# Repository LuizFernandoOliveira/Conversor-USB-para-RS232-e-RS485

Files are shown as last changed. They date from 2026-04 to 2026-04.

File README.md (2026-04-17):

# Conversor USB para RS232 e RS485




## Descrição
Esta PCB trata-se de um circuito eletrônico que transforma uma única porta USB em múltiplos canais de comunicação serial industrial RS232 e/ou RS485.

<p align="center">
  usb2RS232RS485
</p>

---

## Descrições técnicas

- Interface USB: Dispositivo USB High-Speed de 480Mbps;
- Possui quatro canais RS232 (1 ao 4) e quatro canais RS485 (1 ao 4);
- Taxa de Transmissão (Baud Rate): Variável de 1200bps até 6Mbps;
- Alimentação Principal: Requer apenas 3.3V;
- Possui pinos de alimentação de saída de 3.3V e 5V;
- Buffering (FIFO):
  - RX FIFO: 2048 bytes por UART.
  - TX FIFO: 1024 bytes por UART.
- Configurações UART:
  - Bits de Dados: 8 bits;
  - Paridade: Ímpar, Par e Nenhuma;
  - Bits de Parada: 1 ou 2.

---

## Estrutura do repositório
Os arquivos de hardware foram desenvolvidos utilizando o KiCad 9.0.
- **`.kicad_pcb`**: Layout da placa de circuito impresso (Board).
- **`.kicad_sch`**: Esquemático eletrônico do sistema (Schematic).
- **`.kicad_pro`**: Gerenciador de projeto do KiCad (Project).

---

## Autor
**Dr. Luiz Fernando Pinto de Oliveira**

*Engenheiro Eletrônico especializado em Sistemas Embarcados e Ultra-Low Power.*
- **Website:** [FAPLO](https://faplo.webnode.page/)
- **LinkedIn:** [lfpo](https://www.linkedin.com/in/lfpo/)

---

Shield: [][cc-by-nc-nd]

This work is licensed under a
[Creative Commons Attribution-NonCommercial-NoDerivs 4.0 International License][cc-by-nc-nd].

[][cc-by-nc-nd]

[cc-by-nc-nd]: http://creativecommons.org/licenses/by-nc-nd/4.0/
[cc-by-nc-nd-image]: https://licensebuttons.net/l/by-nc-nd/4.0/88x31.png
[cc-by-nc-nd-shield]: https://img.shields.io/badge/License-CC%20BY--NC--ND%204.0-lightgrey.svg

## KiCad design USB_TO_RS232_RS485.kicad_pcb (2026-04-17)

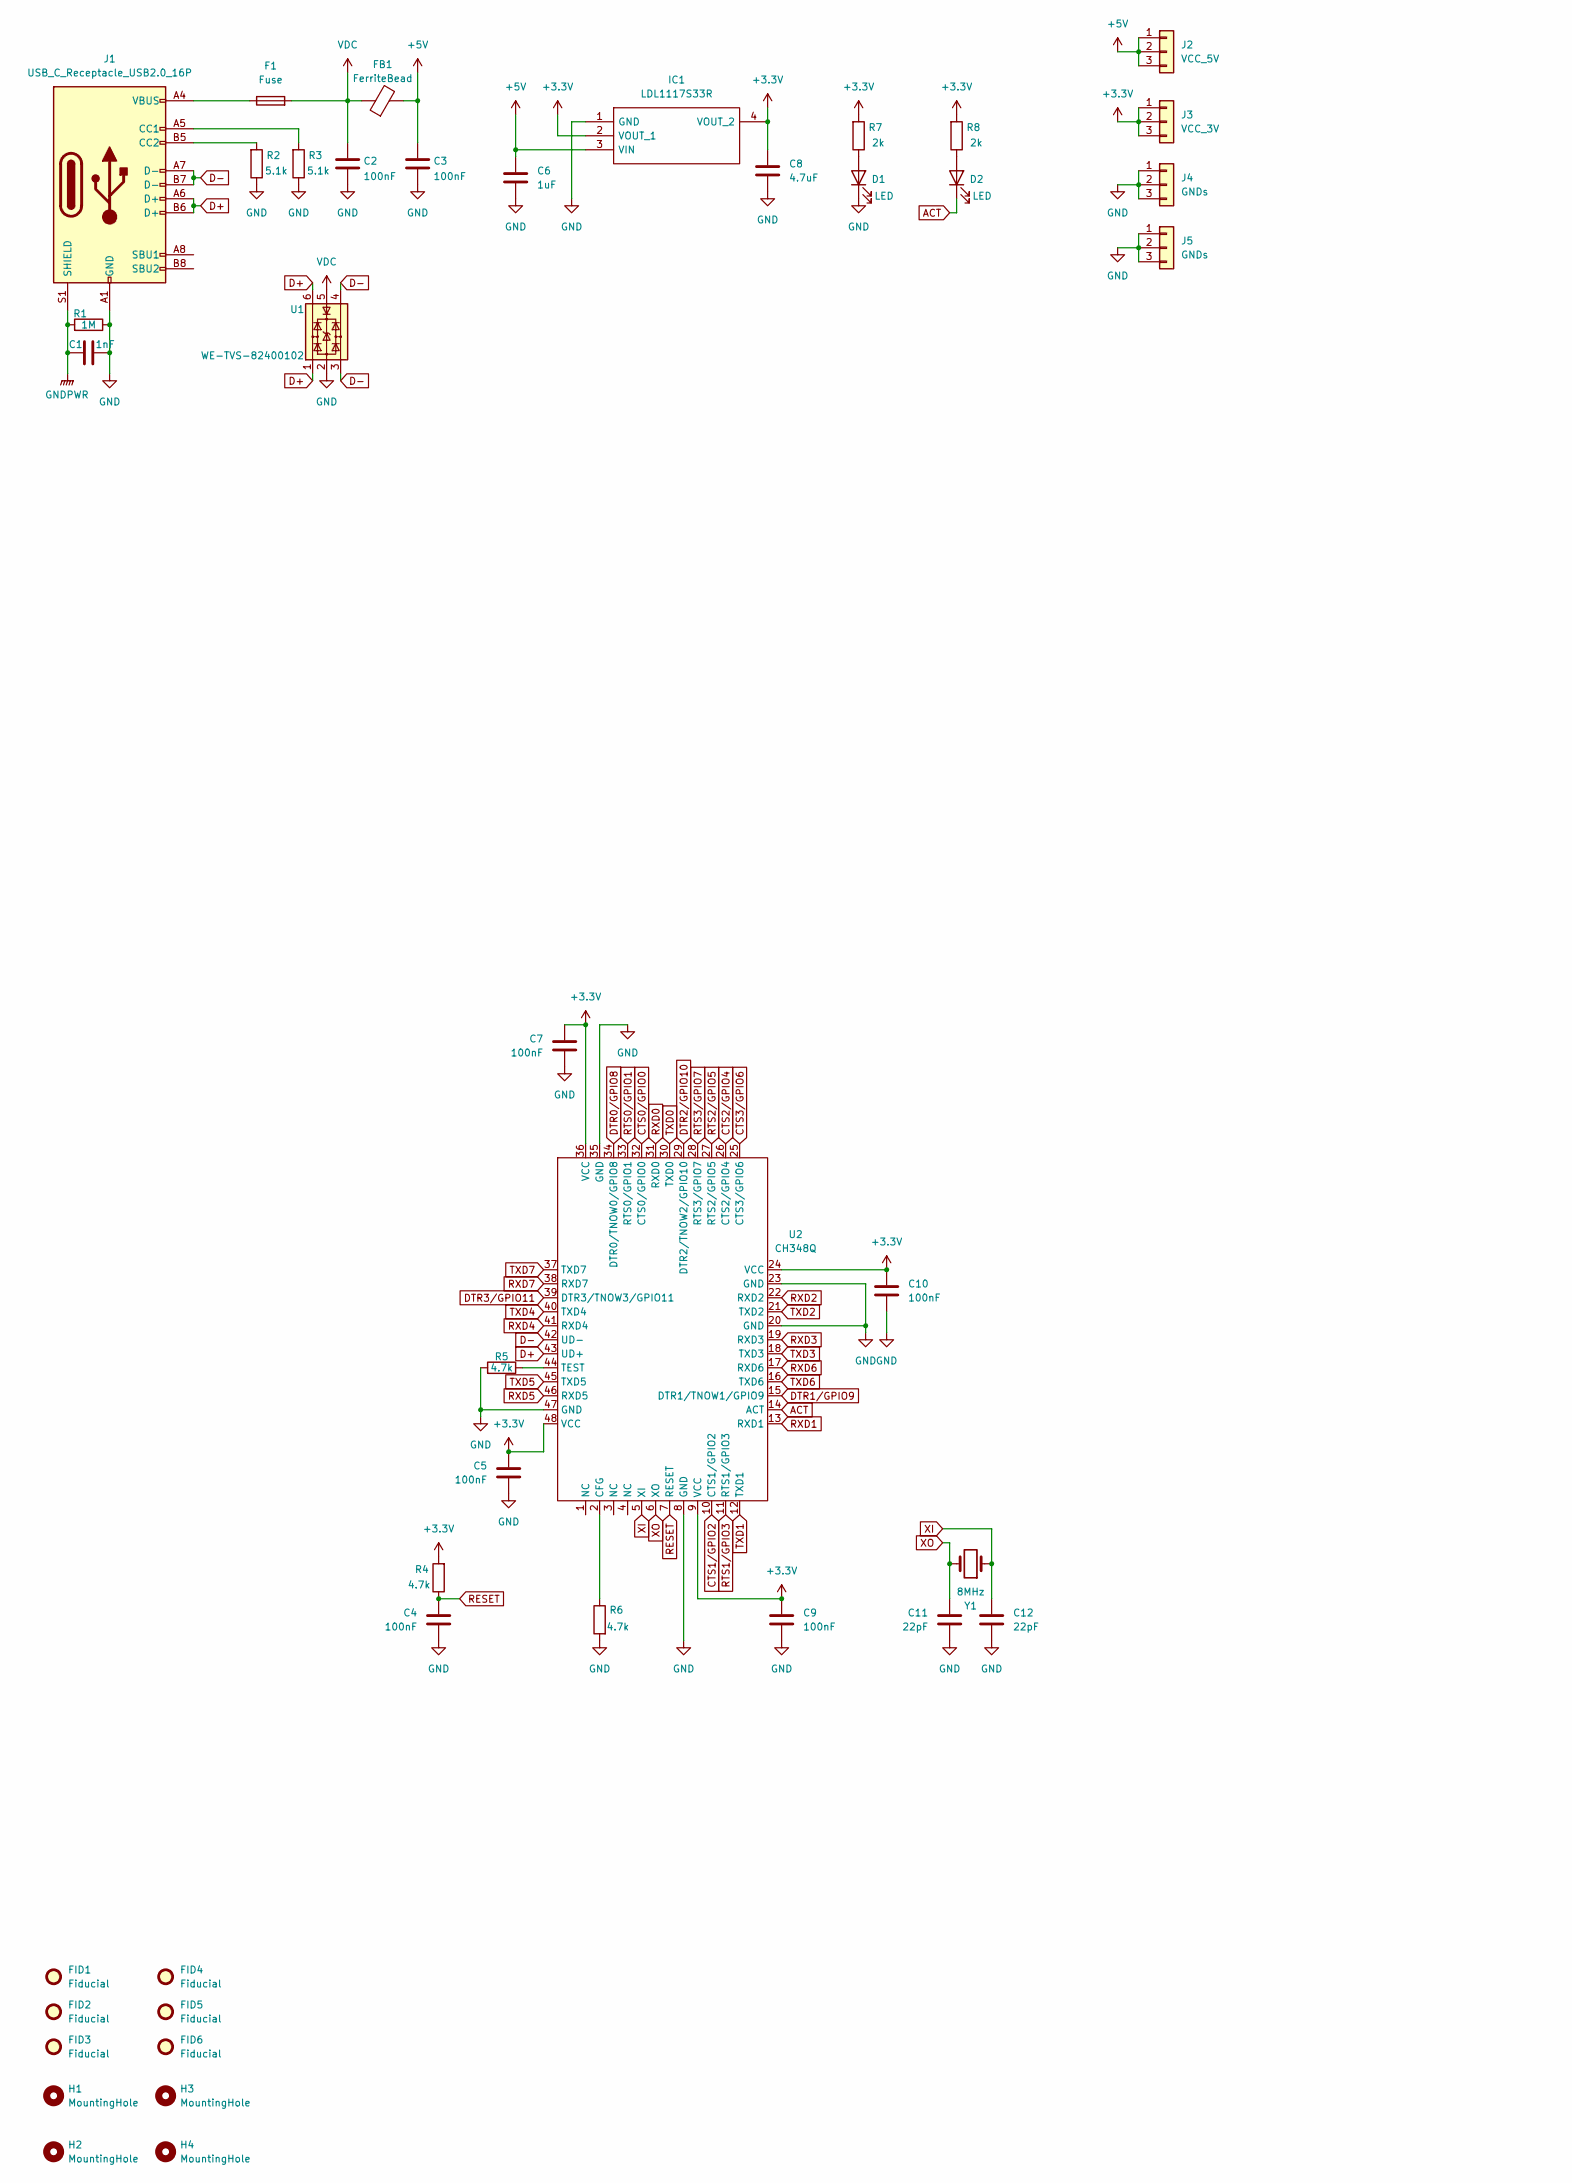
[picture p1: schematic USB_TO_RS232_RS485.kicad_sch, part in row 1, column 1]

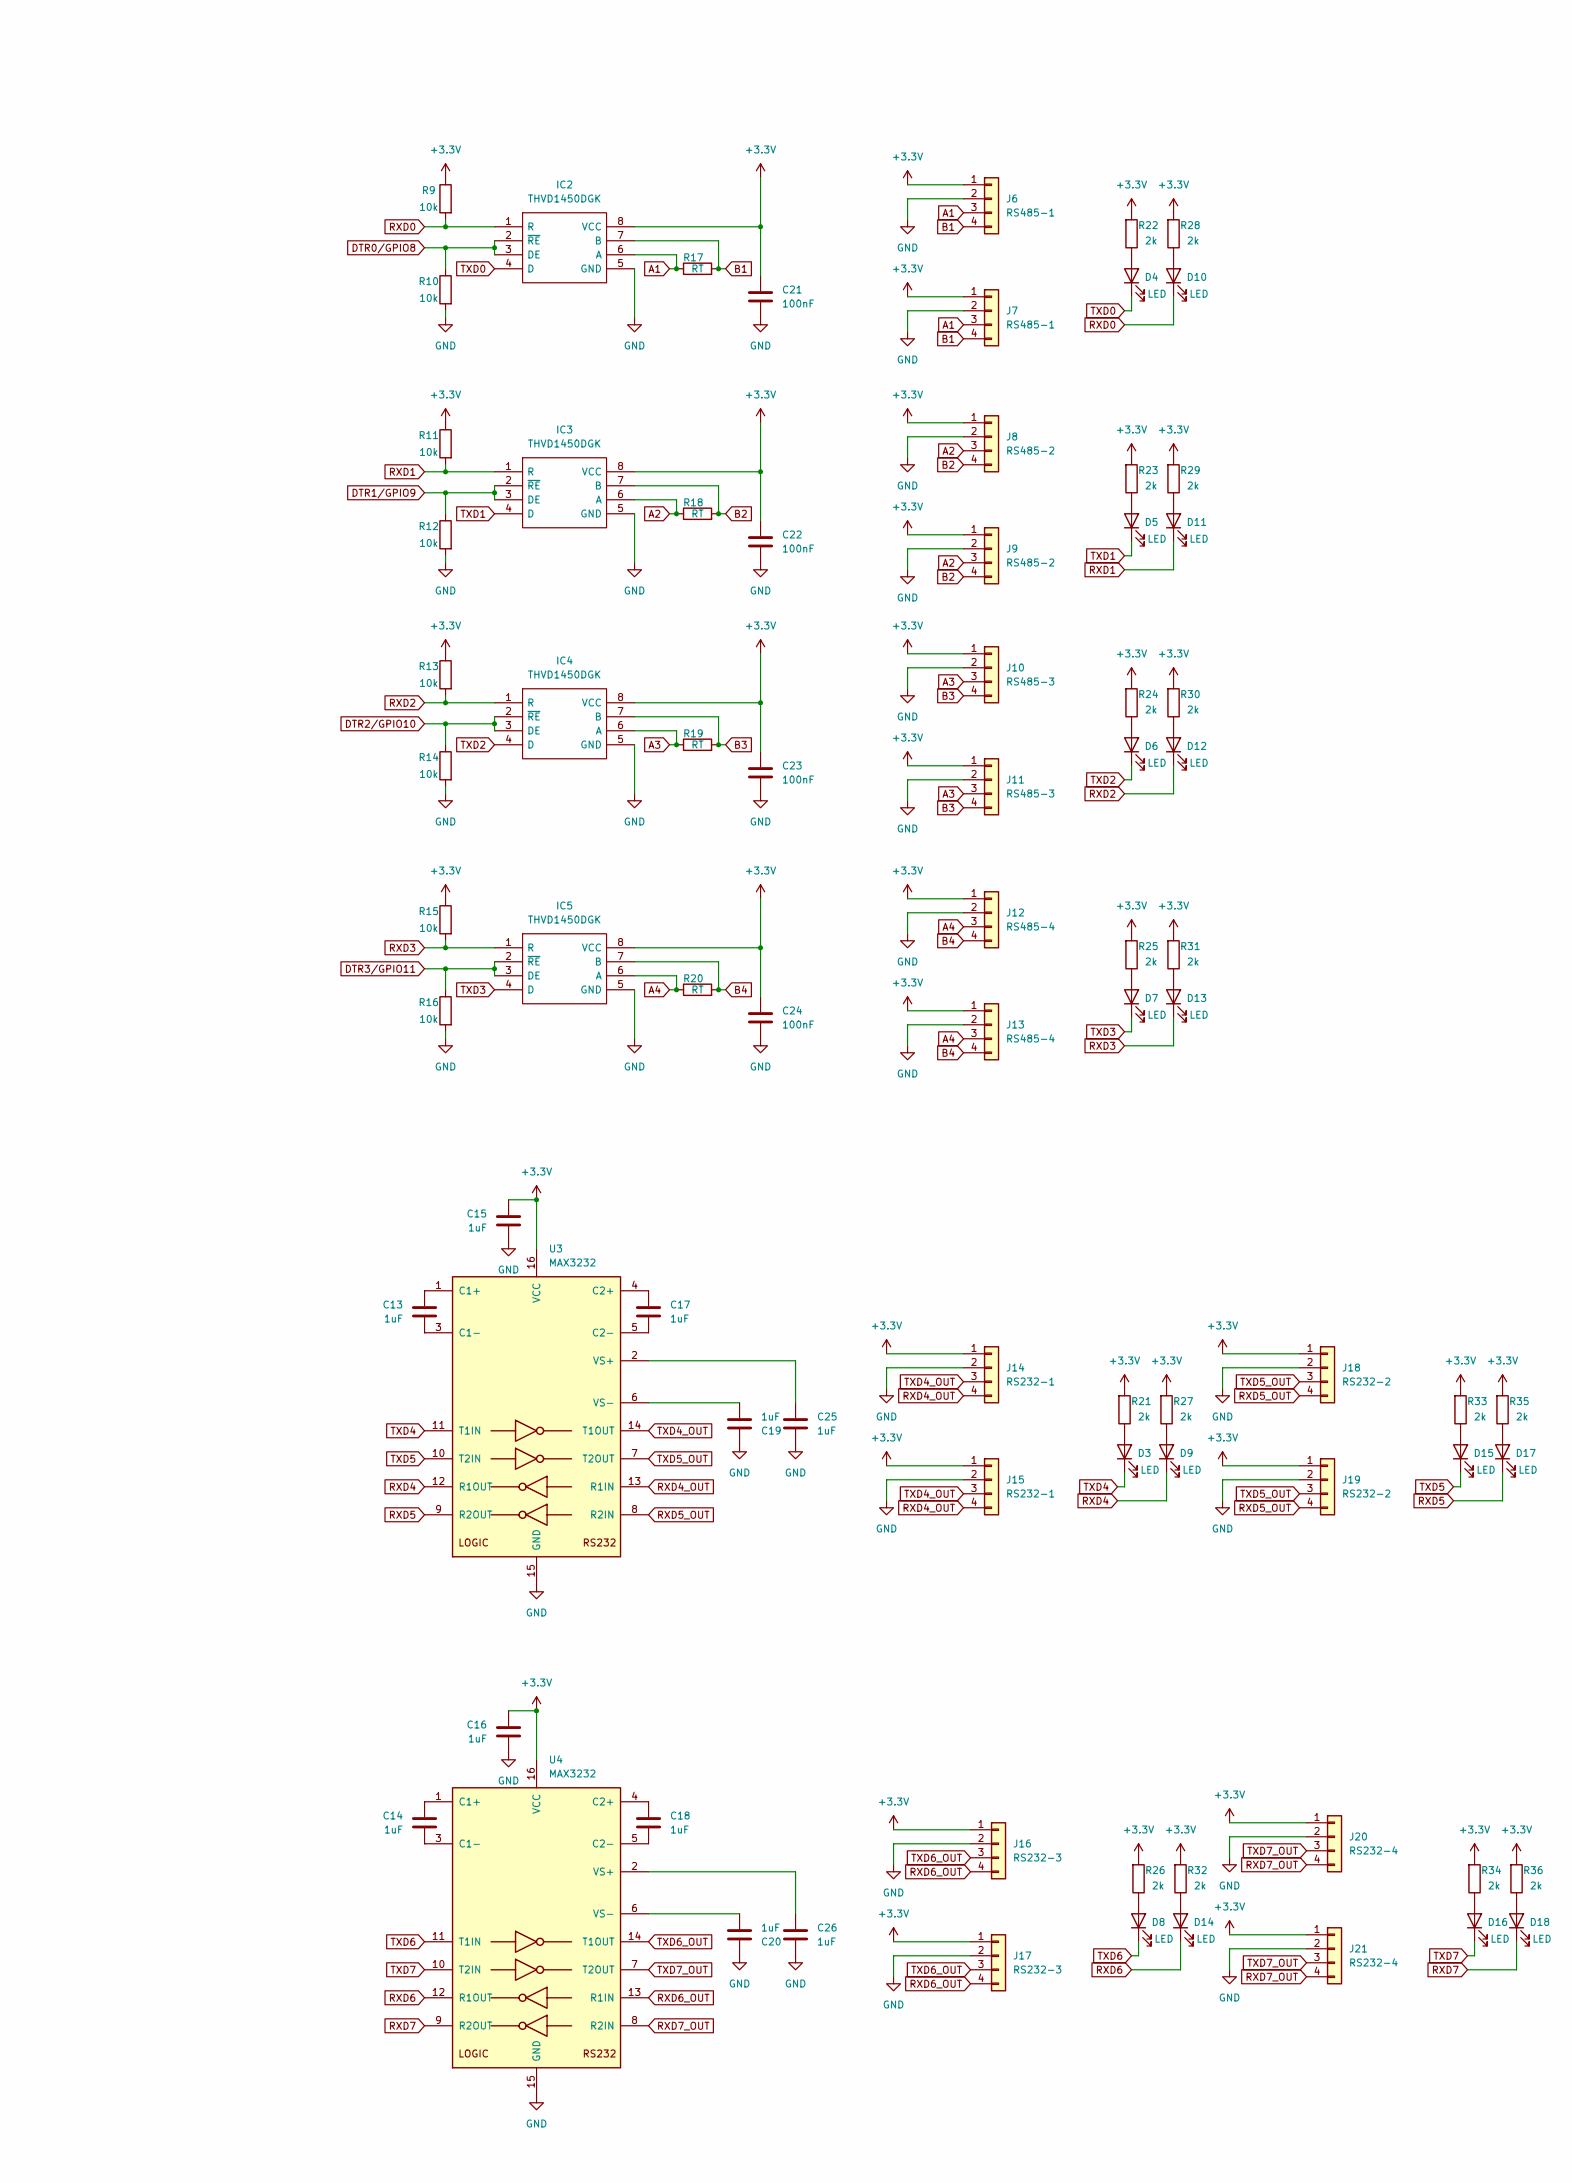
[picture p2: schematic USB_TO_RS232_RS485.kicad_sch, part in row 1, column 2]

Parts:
C1: 1nF; C_0805_2012Metric
C2, C3, C4, C5, C7, C9, C10, C21, C22, C23, C24: 100nF; C_0805_2012Metric
C6, C13, C14, C15, C16, C17, C18, C19, C20, C25, C26: 1uF; C_0805_2012Metric
C8: 4.7uF; C_0805_2012Metric
C11, C12: 22pF; C_0805_2012Metric
D1, D2, D3, D4, D5, D6, D7, D8, D9, D10, D11, D12, D13, D14, D15, D16, D17, D18: LED; LED_0805_2012Metric
F1: Fuse; Fuse_0805_2012Metric
FB1: FerriteBead; L_0805_2012Metric
FID1, FID2, FID3, FID4, FID5, FID6: Fiducial; Fiducial_1mm_Mask2mm
H1, H2, H3, H4: MountingHole; MountingHole_3.2mm_M3_DIN965
IC1: LDL1117S33R; SOT230P700X180-4N; Manufacturer_Part_Number LDL1117S33R; Mouser Part Number 511-LDL1117S33R
IC2, IC3, IC4, IC5: THVD1450DGK; SOP65P490X110-8N; Manufacturer_Part_Number THVD1450DGK; Mouser Part Number 595-THVD1450DGK
J1: USB_C_Receptacle_USB2.0_16P; USB_C_Receptacle_HRO_TYPE-C-31-M-12
J2: VCC_5V; PinHeader_1x03_P2.54mm_Vertical
J3: VCC_3V; PinHeader_1x03_P2.54mm_Vertical
J4, J5: GNDs; PinHeader_1x03_P2.54mm_Vertical
J6: RS485-1; PinHeader_1x04_P2.54mm_Vertical
J7: RS485-1; PhoenixContact_MSTBA_2,5_4-G-5,08_1x04_P5.08mm_Horizontal
J8: RS485-2; PinHeader_1x04_P2.54mm_Vertical
J9: RS485-2; PhoenixContact_MSTBA_2,5_4-G-5,08_1x04_P5.08mm_Horizontal
J10: RS485-3; PinHeader_1x04_P2.54mm_Vertical
J11: RS485-3; PhoenixContact_MSTBA_2,5_4-G-5,08_1x04_P5.08mm_Horizontal
J12: RS485-4; PinHeader_1x04_P2.54mm_Vertical
J13: RS485-4; PhoenixContact_MSTBA_2,5_4-G-5,08_1x04_P5.08mm_Horizontal
J14: RS232-1; PinHeader_1x04_P2.54mm_Vertical
J15: RS232-1; PhoenixContact_MSTBA_2,5_4-G-5,08_1x04_P5.08mm_Horizontal
J16: RS232-3; PinHeader_1x04_P2.54mm_Vertical
J17: RS232-3; PhoenixContact_MSTBA_2,5_4-G-5,08_1x04_P5.08mm_Horizontal
J18: RS232-2; PinHeader_1x04_P2.54mm_Vertical
J19: RS232-2; PhoenixContact_MSTBA_2,5_4-G-5,08_1x04_P5.08mm_Horizontal
J20: RS232-4; PinHeader_1x04_P2.54mm_Vertical
J21: RS232-4; PhoenixContact_MSTBA_2,5_4-G-5,08_1x04_P5.08mm_Horizontal
R1: 1M; R_0805_2012Metric
R2, R3: 5.1k; R_0805_2012Metric
R4, R5, R6: 4.7k; R_0805_2012Metric
R7, R8, R21, R22, R23, R24, R25, R26, R27, R28, R29, R30, R31, R32, R33, R34, R35, R36: 2k; R_0805_2012Metric
R9, R10, R11, R12, R13, R14, R15, R16: 10k; R_0805_2012Metric
R17, R18, R19, R20: RT; R_1206_3216Metric
U1: WE-TVS-82400102; SOT-23-6
U2: CH348Q
U3, U4: MAX3232; TSSOP-16_4.4x5mm_P0.65mm
Y1: 8MHz; Crystal_SMD_3225-4Pin_3.2x2.5mm

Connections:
+3.3V: C5.1, C7.1, C8.1, C9.1, C10.1, C15.1, C16.1, C21.1, C22.1, C23.1, C24.1, IC1.2 (VOUT_1), IC1.4 (VOUT_2), IC2.8 (VCC), IC3.8 (VCC), IC4.8 (VCC), IC5.8 (VCC), J3.1, J3.2, J3.3, J6.1, J7.1, J8.1, J9.1, J10.1, J11.1, J12.1, J13.1, J14.1, J15.1, J16.1, J17.1, J18.1, J19.1, J20.1, J21.1, R4.2, R7.2, R8.2, R9.1, R11.1, R13.1, R15.1, R21.2, R22.2, R23.2, R24.2, R25.2, R26.2, R27.2, R28.2, R29.2, R30.2, R31.2, R32.2, R33.2, R34.2, R35.2, R36.2, U2.9 (VCC), U2.24 (VCC), U2.36 (VCC), U2.48 (VCC), U3.16 (VCC), U4.16 (VCC)
+5V: C3.1, C6.1, FB1.2, IC1.3 (VIN), J2.1, J2.2, J2.3
A1: IC2.6 (A), J6.3, J7.3, R17.1
A2: IC3.6 (A), J8.3, J9.3, R18.1
A3: IC4.6 (A), J10.3, J11.3, R19.1
A4: IC5.6 (A), J12.3, J13.3, R20.1
ACT: D2.1 (K), U2.14 (ACT)
B1: IC2.7 (B), J6.4, J7.4, R17.2
B2: IC3.7 (B), J8.4, J9.4, R18.2
B3: IC4.7 (B), J10.4, J11.4, R19.2
B4: IC5.7 (B), J12.4, J13.4, R20.2
CTS0/GPIO0: U2.32 (CTS0/GPIO0)
CTS1/GPIO2: U2.10 (CTS1/GPIO2)
CTS2/GPIO4: U2.26 (CTS2/GPIO4)
CTS3/GPIO6: U2.25 (CTS3/GPIO6)
D+: J1.A6 (D+), J1.B6 (D+), U1.1, U1.6, U2.43 (UD+)
D-: J1.A7 (D-), J1.B7 (D-), U1.3, U1.4, U2.42 (UD-)
DTR0/GPIO8: IC2.2 (~RE), IC2.3 (DE), R10.1, U2.34 (DTR0/TNOW0/GPIO8)
DTR1/GPIO9: IC3.2 (~RE), IC3.3 (DE), R12.1, U2.15 (DTR1/TNOW1/GPIO9)
DTR2/GPIO10: IC4.2 (~RE), IC4.3 (DE), R14.1, U2.29 (DTR2/TNOW2/GPIO10)
DTR3/GPIO11: IC5.2 (~RE), IC5.3 (DE), R16.1, U2.39 (DTR3/TNOW3/GPIO11)
GND: C1.2, C2.2, C3.2, C4.2, C5.2, C6.2, C7.2, C8.2, C9.2, C10.2, C11.2, C12.2, C15.2, C16.2, C19.1, C20.1, C21.2, C22.2, C23.2, C24.2, C25.2, C26.2, D1.1 (K), IC1.1 (GND), IC2.5 (GND), IC3.5 (GND), IC4.5 (GND), IC5.5 (GND), J1.A1 (GND), J1.A12 (GND), J1.B1 (GND), J1.B12 (GND), J4.1, J4.2, J4.3, J5.1, J5.2, J5.3, J6.2, J7.2, J8.2, J9.2, J10.2, J11.2, J12.2, J13.2, J14.2, J15.2, J16.2, J17.2, J18.2, J19.2, J20.2, J21.2, R1.1, R2.1, R3.1, R5.2, R6.2, R10.2, R12.2, R14.2, R16.2, U1.2, U2.8 (GND), U2.20 (GND), U2.23 (GND), U2.35 (GND), U2.47 (GND), U3.15 (GND), U4.15 (GND)
GNDPWR: C1.1, J1.S1 (SHIELD), R1.2
unnamed: D1.2 (A), R7.1
unnamed: D2.2 (A), R8.1
unnamed: D3.2 (A), R21.1
unnamed: D4.2 (A), R22.1
unnamed: D5.2 (A), R23.1
unnamed: D6.2 (A), R24.1
unnamed: D7.2 (A), R25.1
unnamed: D8.2 (A), R26.1
unnamed: D9.2 (A), R27.1
unnamed: D10.2 (A), R28.1
unnamed: D11.2 (A), R29.1
unnamed: D12.2 (A), R30.1
unnamed: D13.2 (A), R31.1
unnamed: D14.2 (A), R32.1
unnamed: D15.2 (A), R33.1
unnamed: D16.2 (A), R34.1
unnamed: D17.2 (A), R35.1
unnamed: D18.2 (A), R36.1
unnamed: F1.1, J1.A4 (VBUS), J1.A9 (VBUS), J1.B4 (VBUS), J1.B9 (VBUS)
unnamed: J1.A5 (CC1), R3.2
unnamed: J1.B5 (CC2), R2.2
unnamed: R6.1, U2.2 (CFG)
unnamed: R5.1, U2.44 (TEST)
unnamed: C13.1, U3.1 (C1+)
unnamed: C13.2, U3.3 (C1-)
unnamed: C17.1, U3.4 (C2+)
unnamed: C17.2, U3.5 (C2-)
unnamed: C25.1, U3.2 (VS+)
unnamed: C19.2, U3.6 (VS-)
unnamed: C14.1, U4.1 (C1+)
unnamed: C14.2, U4.3 (C1-)
unnamed: C18.1, U4.4 (C2+)
unnamed: C18.2, U4.5 (C2-)
unnamed: C26.1, U4.2 (VS+)
unnamed: C20.2, U4.6 (VS-)
RESET: C4.1, R4.1, U2.7 (RESET)
RTS0/GPIO1: U2.33 (RTS0/GPIO1)
RTS1/GPIO3: U2.11 (RTS1/GPIO3)
RTS2/GPIO5: U2.27 (RTS2/GPIO5)
RTS3/GPIO7: U2.28 (RTS3/GPIO7)
RXD0: D10.1 (K), IC2.1 (R), R9.2, U2.31 (RXD0)
RXD1: D11.1 (K), IC3.1 (R), R11.2, U2.13 (RXD1)
RXD2: D12.1 (K), IC4.1 (R), R13.2, U2.22 (RXD2)
RXD3: D13.1 (K), IC5.1 (R), R15.2, U2.19 (RXD3)
RXD4: D9.1 (K), U2.41 (RXD4), U3.12 (R1OUT)
RXD4_OUT: J14.4, J15.4, U3.13 (R1IN)
RXD5: D17.1 (K), U2.46 (RXD5), U3.9 (R2OUT)
RXD5_OUT: J18.4, J19.4, U3.8 (R2IN)
RXD6: D14.1 (K), U2.17 (RXD6), U4.12 (R1OUT)
RXD6_OUT: J16.4, J17.4, U4.13 (R1IN)
RXD7: D18.1 (K), U2.38 (RXD7), U4.9 (R2OUT)
RXD7_OUT: J20.4, J21.4, U4.8 (R2IN)
TXD0: D4.1 (K), IC2.4 (D), U2.30 (TXD0)
TXD1: D5.1 (K), IC3.4 (D), U2.12 (TXD1)
TXD2: D6.1 (K), IC4.4 (D), U2.21 (TXD2)
TXD3: D7.1 (K), IC5.4 (D), U2.18 (TXD3)
TXD4: D3.1 (K), U2.40 (TXD4), U3.11 (T1IN)
TXD4_OUT: J14.3, J15.3, U3.14 (T1OUT)
TXD5: D15.1 (K), U2.45 (TXD5), U3.10 (T2IN)
TXD5_OUT: J18.3, J19.3, U3.7 (T2OUT)
TXD6: D8.1 (K), U2.16 (TXD6), U4.11 (T1IN)
TXD6_OUT: J16.3, J17.3, U4.14 (T1OUT)
TXD7: D16.1 (K), U2.37 (TXD7), U4.10 (T2IN)
TXD7_OUT: J20.3, J21.3, U4.7 (T2OUT)
VDC: C2.1, F1.2, FB1.1, U1.5
XI: C12.1, U2.5 (XI), Y1.1
XO: C11.1, U2.6 (XO), Y1.2

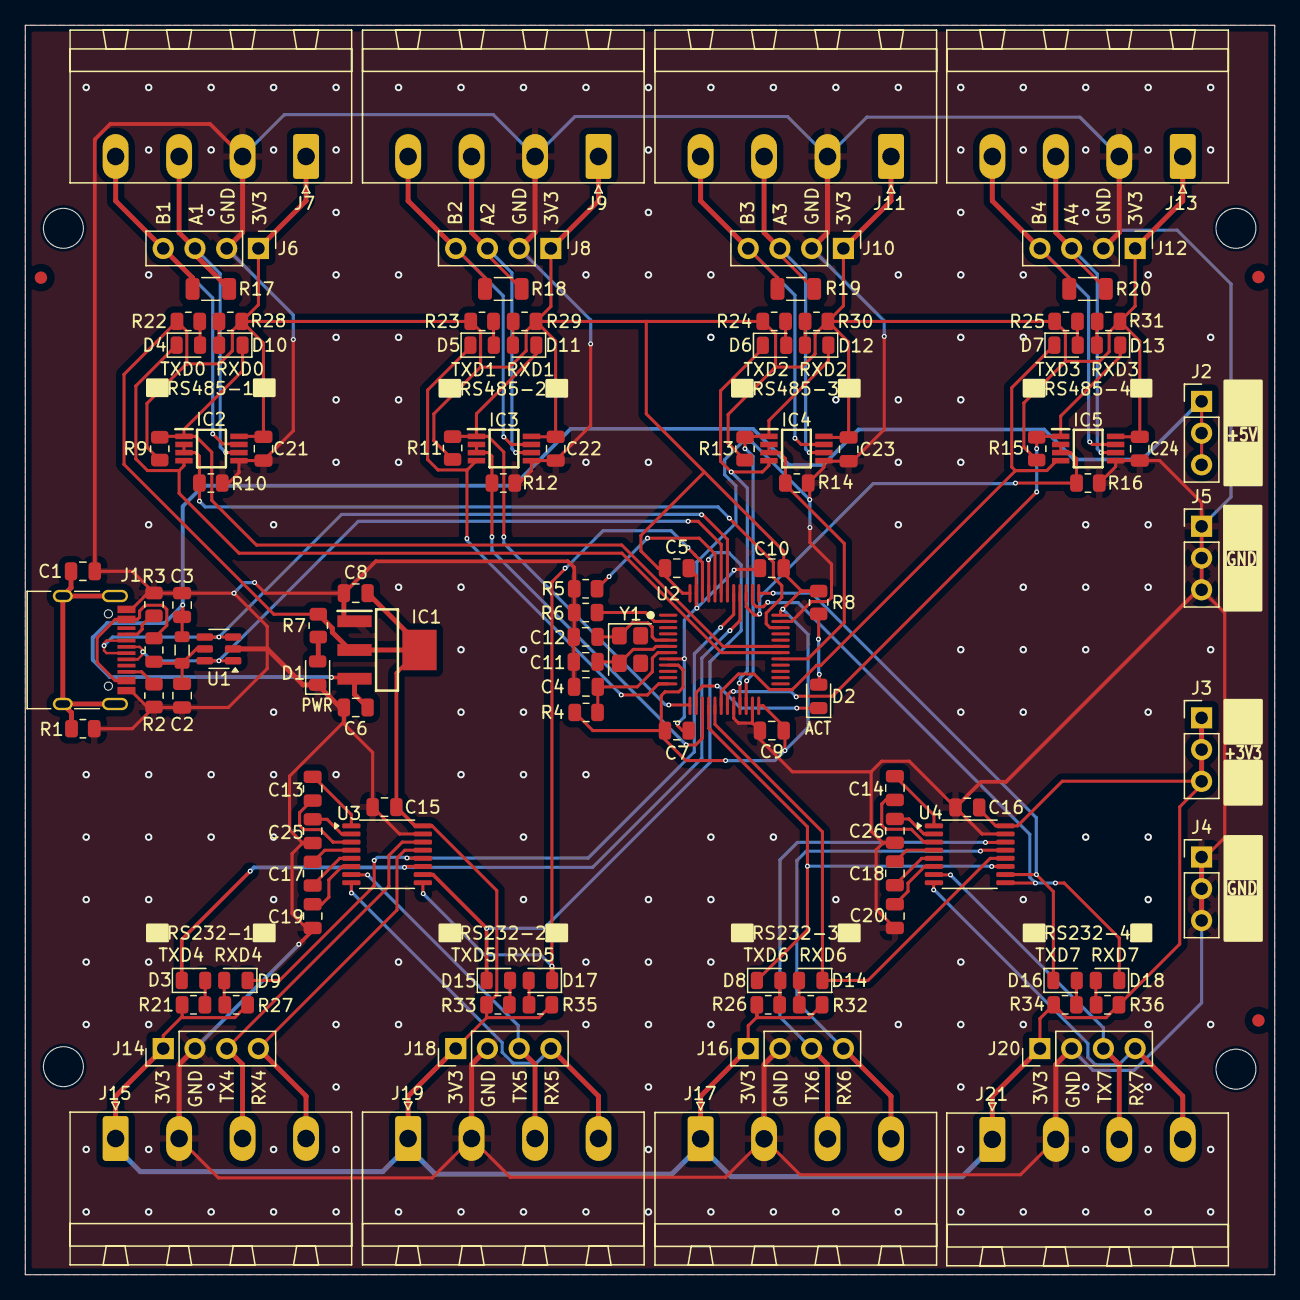
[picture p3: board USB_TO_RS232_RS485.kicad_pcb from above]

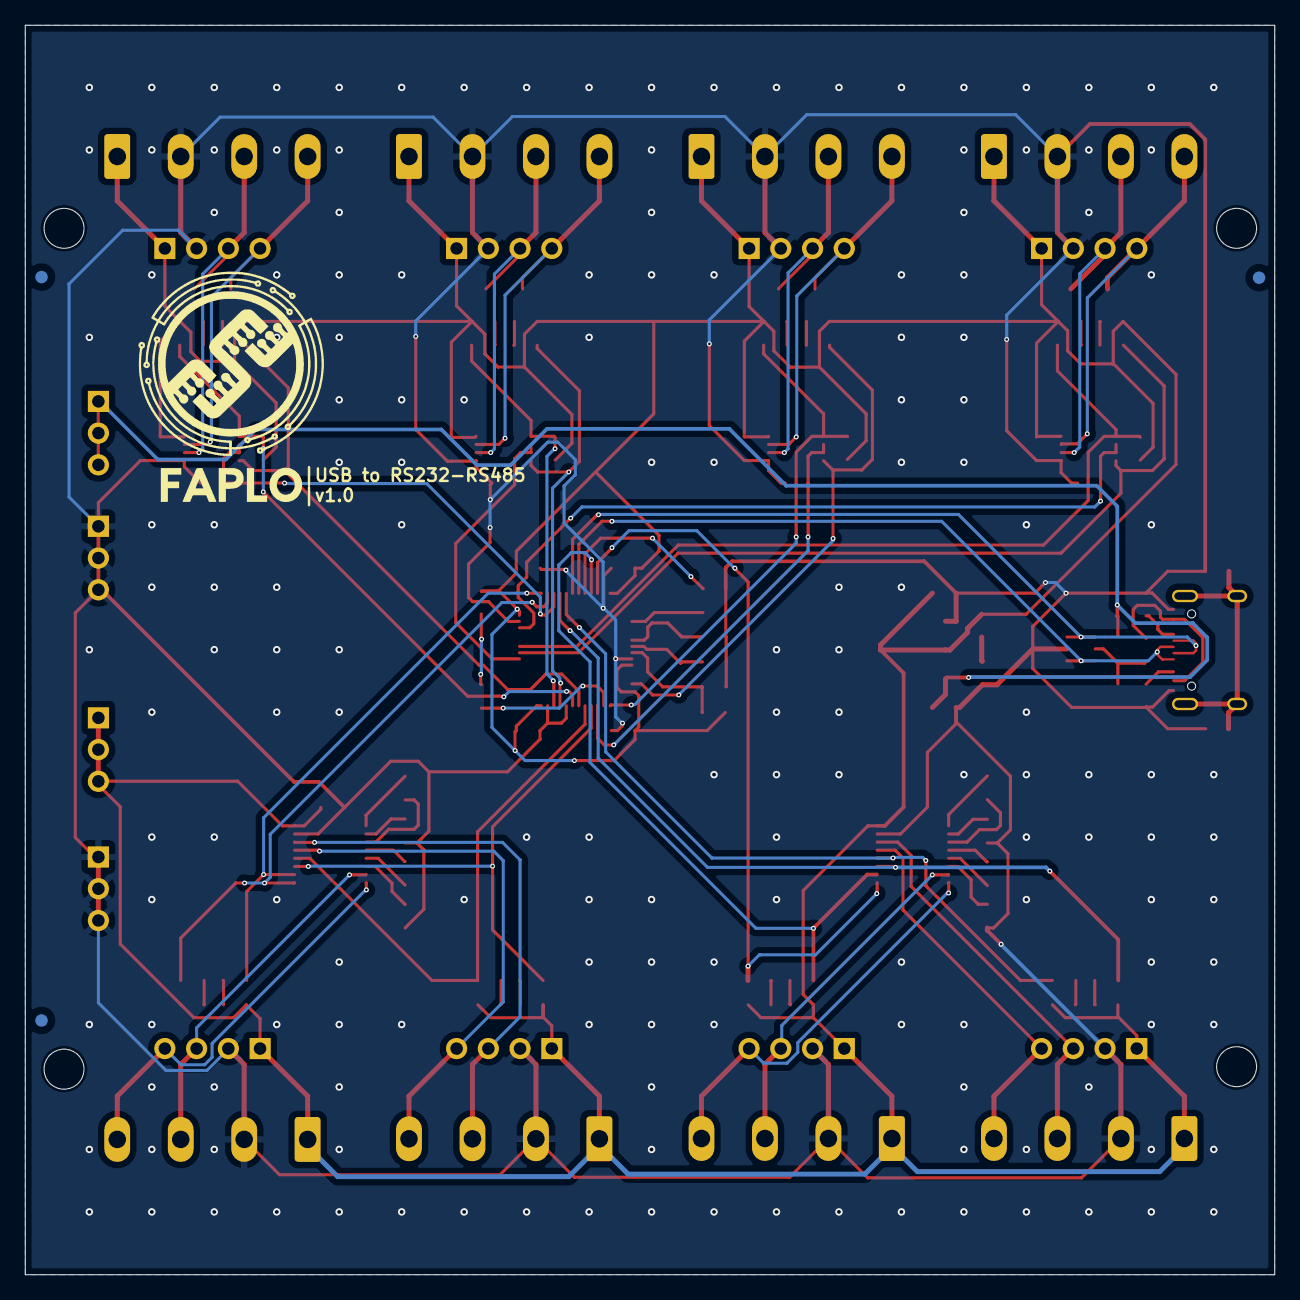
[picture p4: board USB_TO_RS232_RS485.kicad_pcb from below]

Board: 2 copper layers, 100.0 x 100.0 mm, 123 parts (3 on the bottom side), 82 nets.

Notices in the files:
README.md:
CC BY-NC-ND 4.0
